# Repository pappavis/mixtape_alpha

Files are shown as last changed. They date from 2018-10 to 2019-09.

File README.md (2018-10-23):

# Wat is Mixtape Alpha?
MixTape Alpga is 'n Atmel328P (Arduino) gebasseerd aanraakgevoelig synth.  Die projekbestande omvat schema bestand vir EagleCAD en diebronkode om dit te laat werk. <br/><br/>
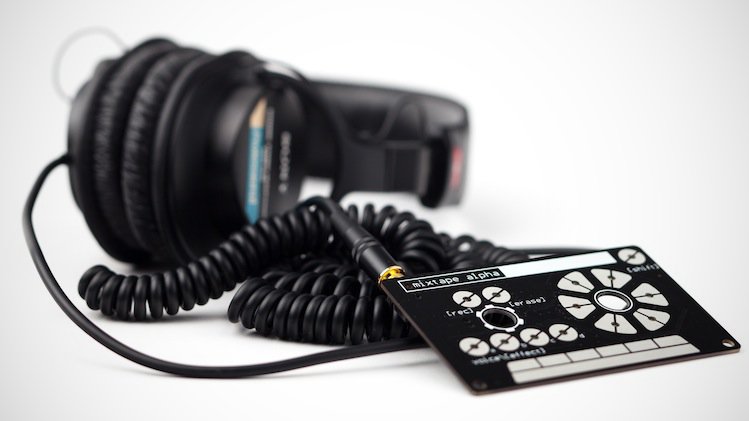
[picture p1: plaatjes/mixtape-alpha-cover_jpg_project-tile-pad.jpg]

<br/>

## Gebruiksinstruksies:<br/>
1. Download EagleCAD<br/>
2. Laai die Schema bestand in Eagle en bekyk dit.<br/>
<br/>

## Printplaat laat maak?<br/>
Om self printplate te laat maak, upload die GERBERs mixtape2_gerber.zip na 'n diens soos http://JLCPCB.com of http://dirtypcbs.com<br/>
<br/>

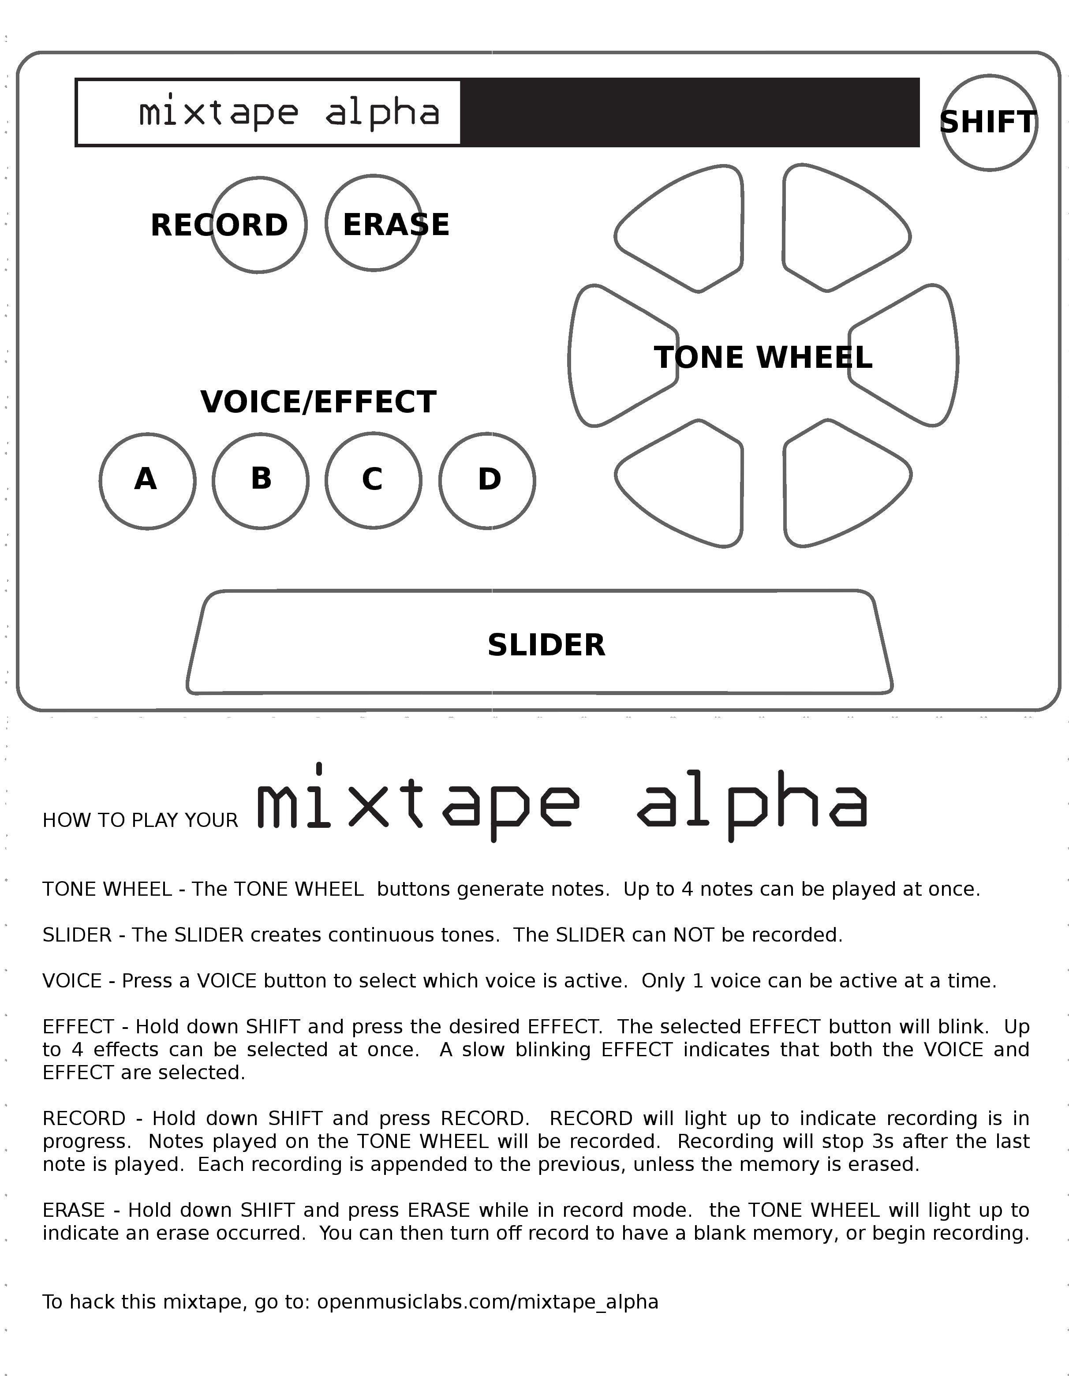
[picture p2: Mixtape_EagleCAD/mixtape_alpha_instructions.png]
<br/>
<br/>

# CREDITS:
Die oorspronklike Mixtape project uit 2013 van MIT Music Lab is op http://wiki.openmusiclabs.com/wiki/MixtapeAlpha<br/>
Ook was daar 'n crowdfunding projek op https://www.crowdsupply.com/open-music-labs/mixtape-alpha <br/>
Ek het dit vir gemak op Github geplaas.<br/>
<br/>

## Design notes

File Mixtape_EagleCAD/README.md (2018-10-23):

## Wat is dit
Dit is die bronbestanden vir EagleCAD en gerbers om by http://jlcpcb.com te laat maak.

## Schema
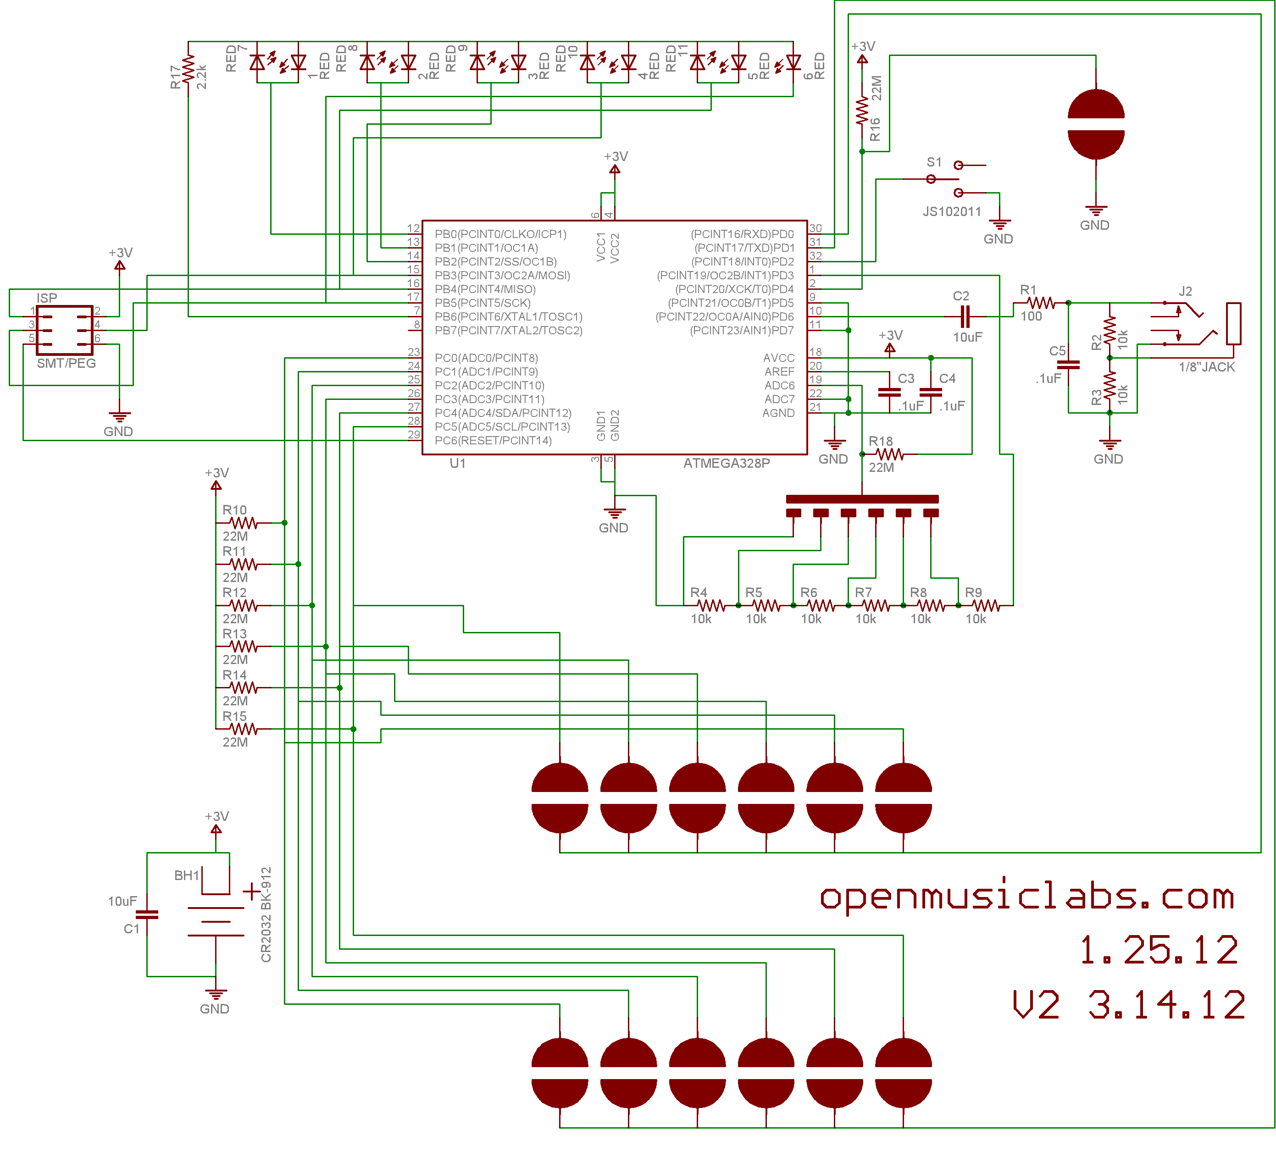
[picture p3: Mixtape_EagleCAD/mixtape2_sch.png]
<br/>
<br/>
## Printplaat boven
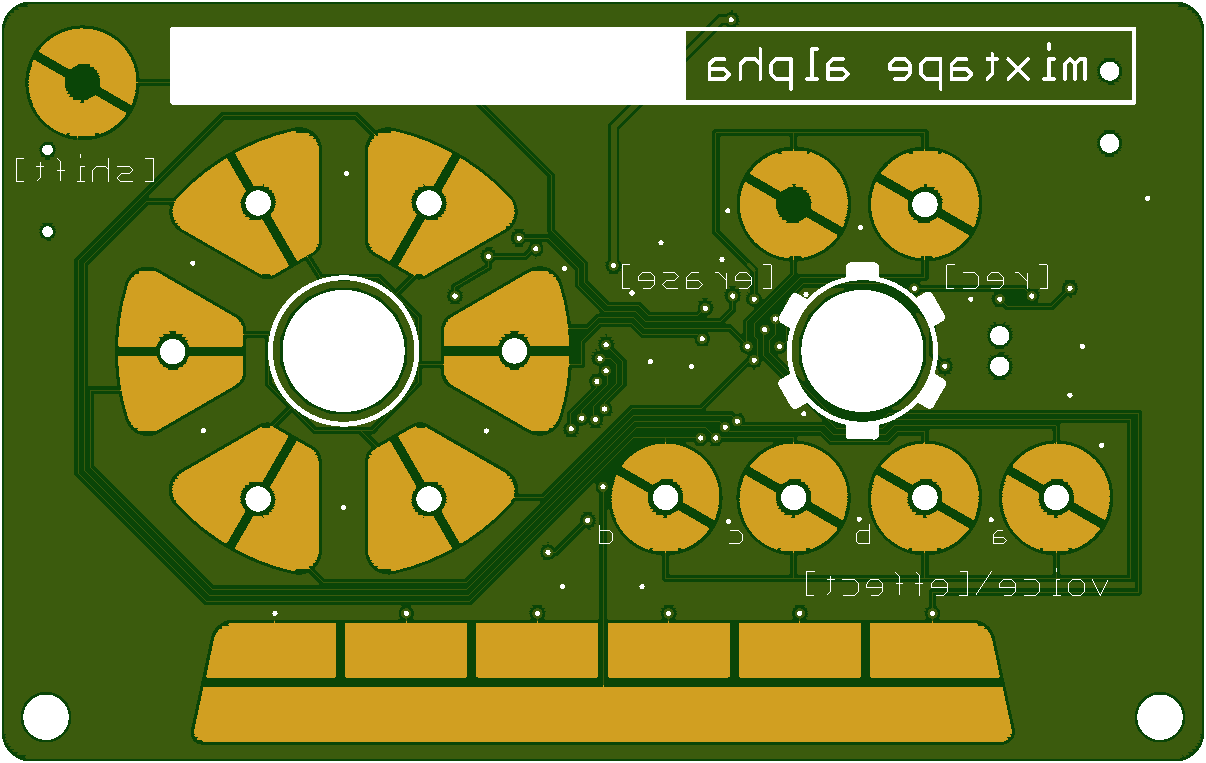
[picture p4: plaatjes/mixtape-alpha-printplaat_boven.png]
 <br/>
<br/>

## Printplaat onder
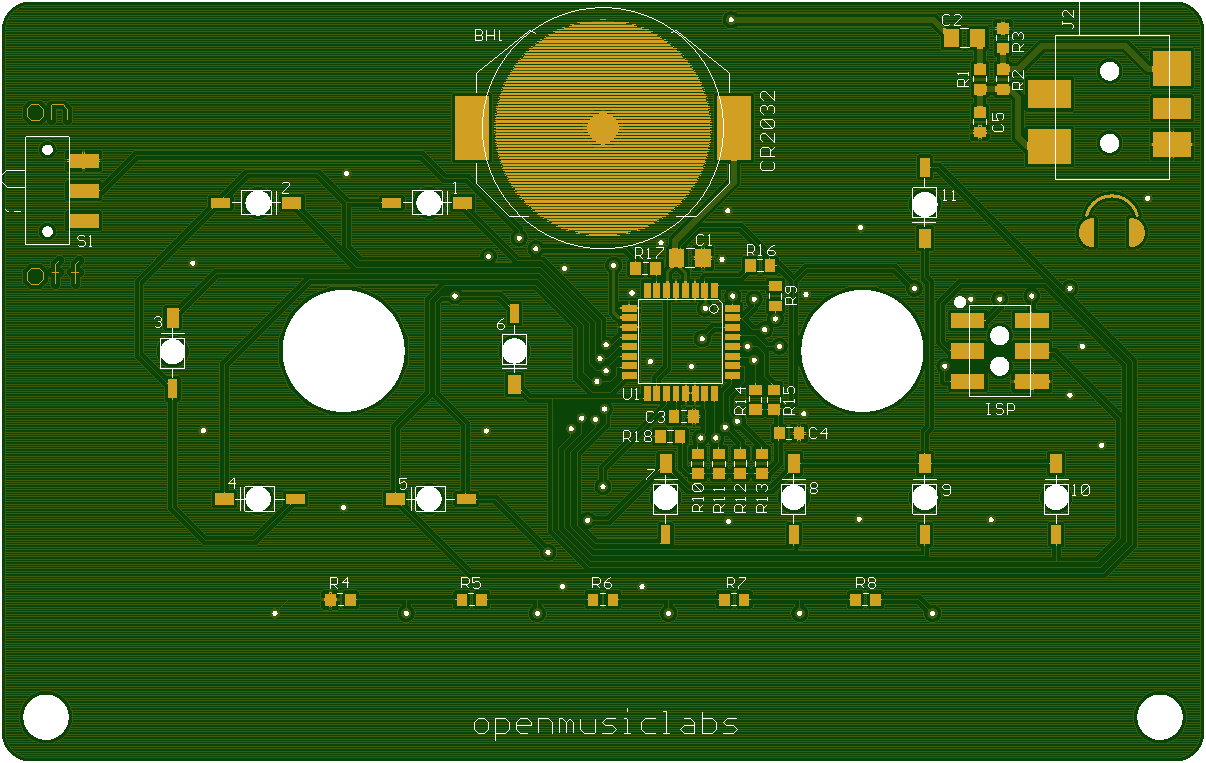
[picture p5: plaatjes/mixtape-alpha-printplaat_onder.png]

<br>

## Dokumentasie
sien wiki op http://wiki.openmusiclabs.com/wiki/MixtapeAlpha <br/>
en algemeen info op http://www.openmusiclabs.com/projects/mixtape_alpha/ <br/>

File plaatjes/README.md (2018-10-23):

Mixtape agterkant met Atmel 328P verwerker;<br/><br/>
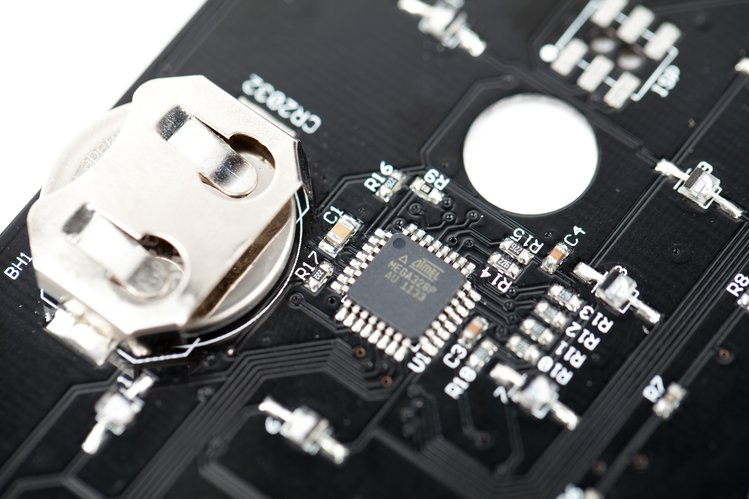
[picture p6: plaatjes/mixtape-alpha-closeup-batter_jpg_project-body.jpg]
<br/>
<br/>
# bord schema ontwerp
<br/>

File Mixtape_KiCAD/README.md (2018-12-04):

<br/>
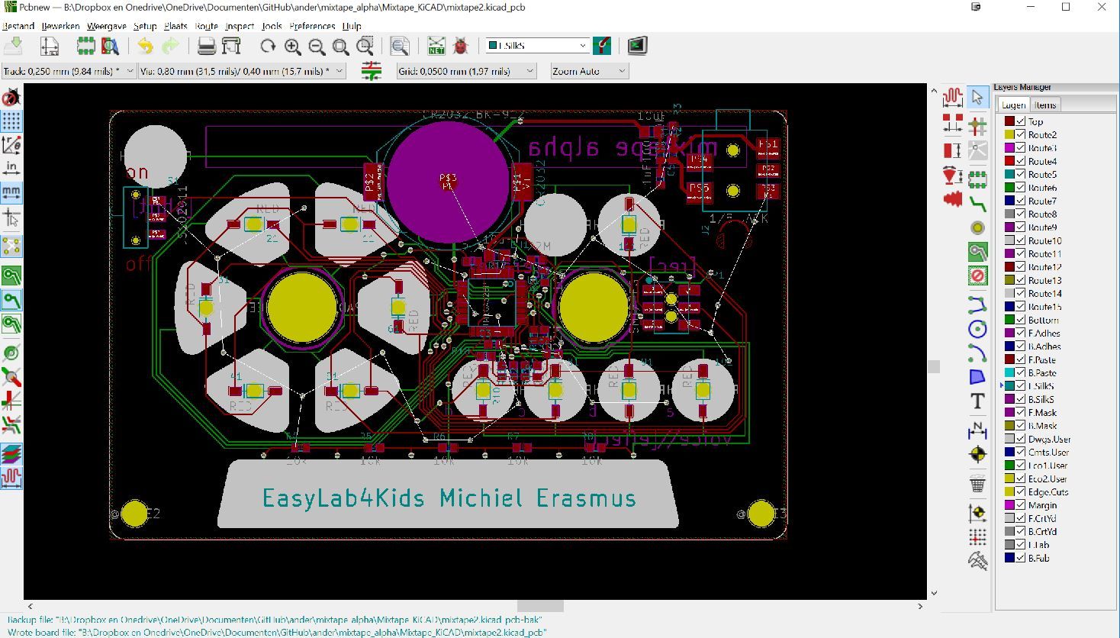
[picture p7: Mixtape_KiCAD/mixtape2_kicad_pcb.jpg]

<br/>

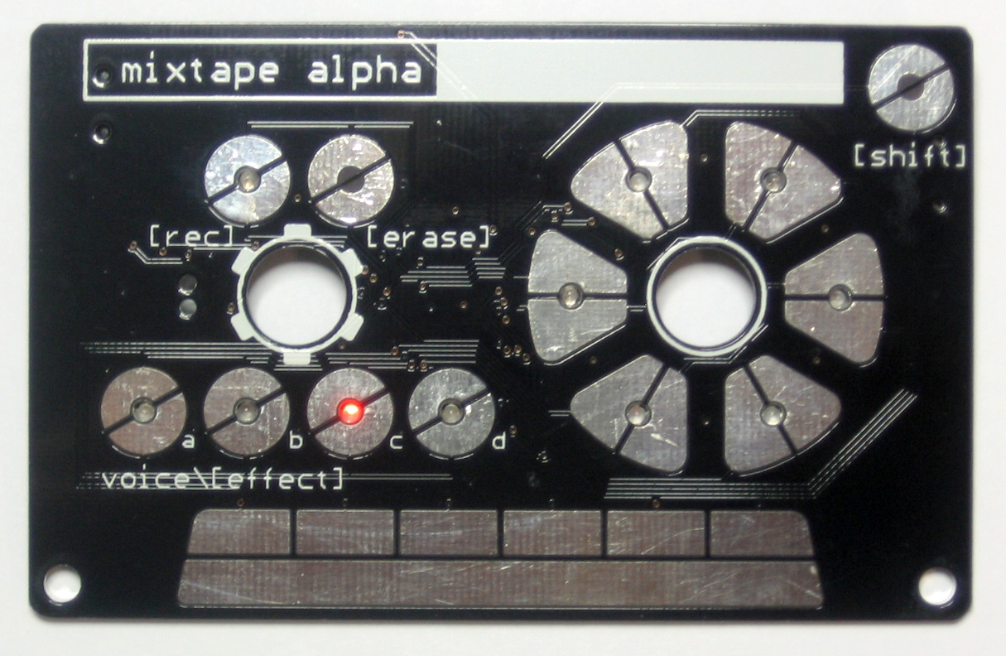
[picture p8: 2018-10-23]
plaatjes/mixtape_top.jpg

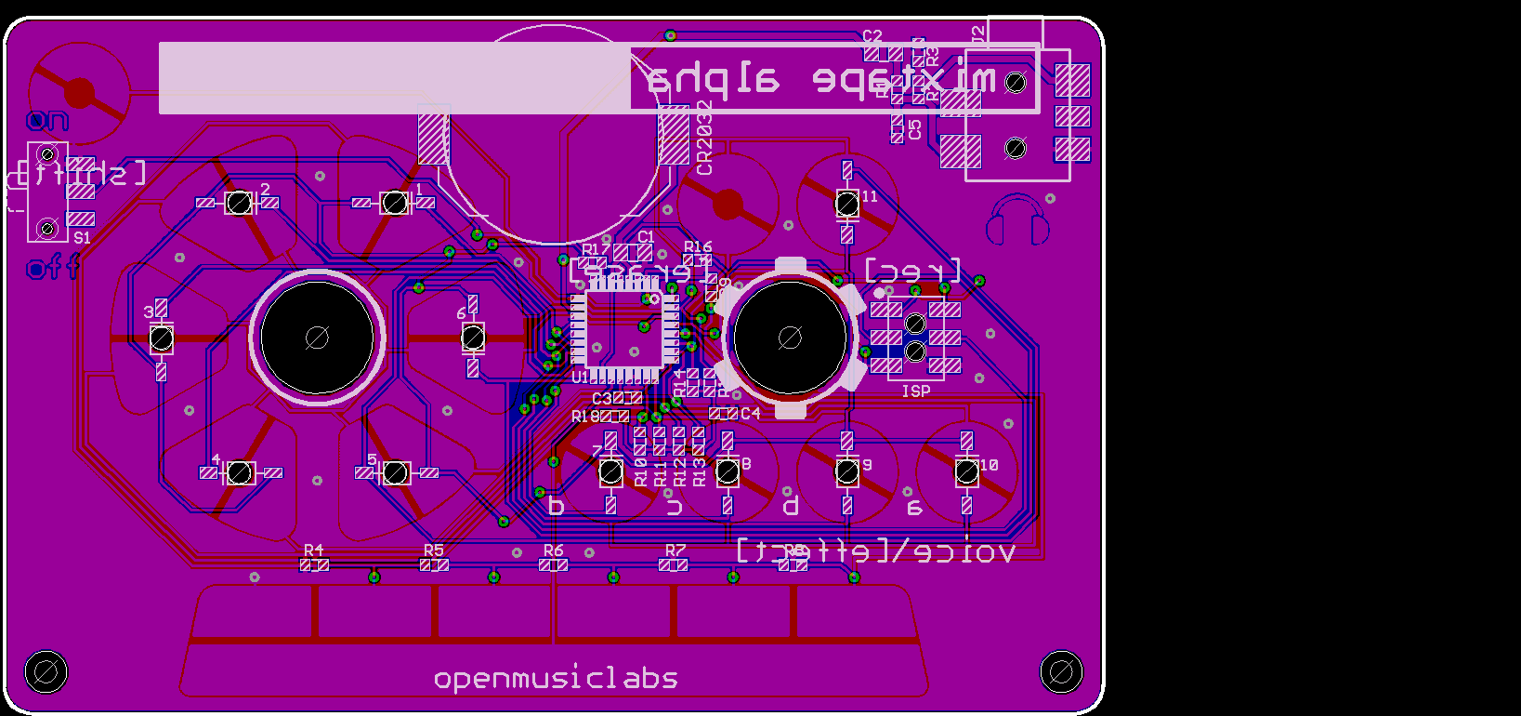
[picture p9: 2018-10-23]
Mixtape_EagleCAD/mixtape2_brd.png

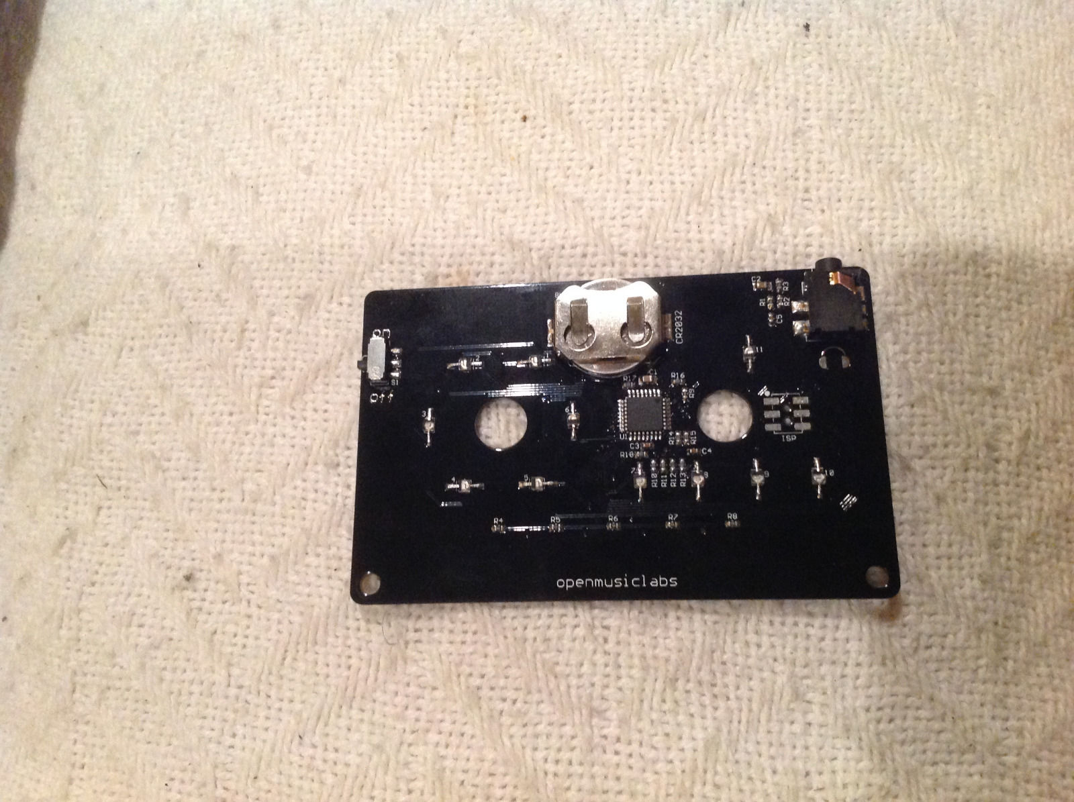
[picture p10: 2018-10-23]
plaatjes/mixtape-alpha-closeup-agter.jpg

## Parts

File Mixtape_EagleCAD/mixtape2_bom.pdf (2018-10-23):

Mixtape1 BOM

DESIGNATOR | PART | VALUE | PACKAGE | DETAILS | PART #
1 | LED | RED | SMT/REVERSE | 25 degree, 482mCd | EVERLIGHT, 91-21SURC/S530-A2/TR10
2 | LED | RED | SMT/REVERSE | 25 degree, 482mCd | EVERLIGHT, 91-21SURC/S530-A2/TR10
3 | LED | RED | SMT/REVERSE | 25 degree, 482mCd | EVERLIGHT, 91-21SURC/S530-A2/TR10
4 | LED | RED | SMT/REVERSE | 25 degree, 482mCd | EVERLIGHT, 91-21SURC/S530-A2/TR10
5 | LED | RED | SMT/REVERSE | 25 degree, 482mCd | EVERLIGHT, 91-21SURC/S530-A2/TR10
6 | LED | RED | SMT/REVERSE | 25 degree, 482mCd | EVERLIGHT, 91-21SURC/S530-A2/TR10
7 | LED | RED | SMT/REVERSE | 25 degree, 482mCd | EVERLIGHT, 91-21SURC/S530-A2/TR10
8 | LED | RED | SMT/REVERSE | 25 degree, 482mCd | EVERLIGHT, 91-21SURC/S530-A2/TR10
9 | LED | RED | SMT/REVERSE | 25 degree, 482mCd | EVERLIGHT, 91-21SURC/S530-A2/TR10
10 | LED | RED | SMT/REVERSE | 25 degree, 482mCd | EVERLIGHT, 91-21SURC/S530-A2/TR10
11 | LED | RED | SMT/REVERSE | 25 degree, 482mCd | EVERLIGHT, 91-21SURC/S530-A2/TR10
U1 | | Atmega328P-AU | 32TQFP
C1 | capacitor | 10uF | 0805 | CERAMIC
C2 | capacitor | 10uF | 0805 | CERAMIC
C3 | capacitor | 0.1uF | 0603 | CERAMIC
C4 | capacitor | 0.1uF | 0603 | CERAMIC
C5 | capacitor | 0.1uF | 0603 | CERAMIC
R1 | resistor | 100ohm | 0603
R2 | resistor | 10k | 0603
R3 | resistor | 10k | 0603
R4 | resistor | 10k | 0603
R5 | resistor | 10k | 0603
R6 | resistor | 10k | 0603
R7 | resistor | 10k | 0603
R8 | resistor | 10k | 0603
R9 | resistor | 10k | 0603
R10 | resistor | 22M | 0603
R11 | resistor | 22M | 0603
R12 | resistor | 22M | 0603
R13 | resistor | 22M | 0603
R14 | resistor | 22M | 0603
R15 | resistor | 22M | 0603
R16 | resistor | 22M | 0603
R17 | resistor | 2.2k | 0603
R18 | resistor | 22M | 0603
S1 | switch | slide | SMT | | C&K, JS102011SAQN
J2 | 1/8” jack | stereo/switched | SMT
BH1 | battery holder | CR2032 | SMT | | MEMORY PROTECTION DEVICES, BK-912

uC

Kobiconn 161-2805-E or CUI SJ1-3515-SMT

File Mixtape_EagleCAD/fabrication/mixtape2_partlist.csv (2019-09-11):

Partlist
Exported from mixtape2.brd at 11-9-2019 18:00
EAGLE Version 9.0.1 Copyright (c) 1988-2018 Autodesk, Inc.
Assembly variant:
Part     Value                  Package               Library  Position (inch)       Orientation
1        RED                    LED-SMT-91-21         audioint (1.405 1.835)         R180
2        RED                    LED-SMT-91-21         audioint (0.845 1.835)         R180
3        RED                    LED-SMT-91-21         audioint (0.565 1.348)         R270
4        RED                    LED-SMT-91-21         audioint (0.845 0.865)         R0
5        RED                    LED-SMT-91-21         audioint (1.405 0.865)         R0
6        RED                    LED-SMT-91-21         audioint (1.685 1.35)          R90
7        RED                    LED-SMT-91-21         audioint (2.18 0.87)           R270
8        RED                    LED-SMT-91-21         audioint (2.6 0.87)            R270
9        RED                    LED-SMT-91-21         audioint (3.03 0.87)           R270
10       RED                    LED-SMT-91-21         audioint (3.46 0.87)           R270
11       RED                    LED-SMT-91-21         audioint (3.03 1.83)           R90
BH1      CR2032 BK-912          BAT-HOLD-BK-912       audioint (1.975 2.08)          R180
C1       10uF                   0805/SMALL            audioint (2.26 1.655)          R180
C2       10uF                   0805/SMALL            audioint (3.16 2.375)          R180
C3       .1uF                   0603-SM               audioint (2.24 1.135)          R0
C4       .1uF                   0603-SM               audioint (2.585 1.08)          R0
C5       .1uF                   0603-SM               audioint (3.21 2.1)            R270
ISP      SMT/PEG                JMP/6P/DIP/SMT/PEG    audioint (3.275 1.35)          R270
J2       1/8"JACK               1/8"JACK/STEREO/SMT   audioint (3.635 2.385)         R0
R1       100                    0603-SM               audioint (3.21 2.24)           R270
R2       10k                    0603-SM               audioint (3.285 2.24)          R270
R3       10k                    0603-SM               audioint (3.285 2.375)         R270
R4       10k                    0603-SM               audioint (1.115 0.535)         R0
R5       10k                    0603-SM               audioint (1.545 0.535)         R0
R6       10k                    0603-SM               audioint (1.975 0.535)         R0
R7       10k                    0603-SM               audioint (2.405 0.535)         R0
R8       10k                    0603-SM               audioint (2.835 0.535)         R0
R9       10k                    0603-SM               audioint (2.54 1.53)           R90
R10      22M                    0603-SM               audioint (2.285 0.98)          R90
R11      22M                    0603-SM               audioint (2.355 0.98)          R90
R12      22M                    0603-SM               audioint (2.425 0.98)          R90
R13      22M                    0603-SM               audioint (2.495 0.98)          R90
R14      22M                    0603-SM               audioint (2.475 1.19)          R90
R15      22M                    0603-SM               audioint (2.535 1.19)          R90
R16      22M                    0603-SM               audioint (2.49 1.63)           R180
R17      100                    0603-SM               audioint (2.115 1.62)          R180
R18      22M                    0603-SM               audioint (2.195 1.07)          R0
S1       JS102011               SWITCH/SLIDE/JS102011 audioint (0.155 1.875)         R270
U$1      PAD/TOUCH/WHEEL        PAD/TOUCH/WHEEL       audioint (1.125 1.35)          MR0
U$2      PAD/TOUCH              PAD/TOUCH/DOT         audioint (2.18 0.87)           MR0
U$3      PAD/TOUCH              PAD/TOUCH/DOT         audioint (2.6 0.87)            MR0
U$4      PAD/TOUCH              PAD/TOUCH/DOT         audioint (3.03 0.87)           MR0
U$5      PAD/TOUCH              PAD/TOUCH/DOT         audioint (3.46 0.87)           MR0
U$6      PAD/TOUCH              PAD/TOUCH/DOT         audioint (3.03 1.83)           MR180
U$7      PAD/TOUCH              PAD/TOUCH/DOT         audioint (2.6 1.83)            MR180
U$8      PAD/TOUCH              PAD/TOUCH/DOT         audioint (0.27 2.23)           MR0
U$9      PAD/TOUCH/SLIDERSLIDER PAD/TOUCH/SLIDER      audioint (1.975 0.265)         MR0
U1       ATMEGA328P             32-TQFP-NOMOD         audioint (2.23 1.38)           R270

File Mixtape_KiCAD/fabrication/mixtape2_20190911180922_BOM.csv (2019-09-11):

ID | Name | Designator | Footprint | Quantity | Manufacturer Part | Manufacturer | Supplier | Supplier Part
1 | PAD/TOUCH/WHEEL | U$1 | PAD/TOUCH/WHEEL | 1
2 | PAD/TOUCH | U$2,U$3,U$4,U$5,U$6,U$7,U$8 | PAD/TOUCH/DOT | 7
3 | PAD/TOUCH/SLIDERSLIDER | U$9 | PAD/TOUCH/SLIDER | 1
4 | 1/8"JACK | J2 | 1/8&quot;JACK/STEREO/SMT | 1
5 | CR2032 BK-912 | BH1 | BAT-HOLD-BK-912 | 1
6 | ATMEGA328P | U1 | 32-TQFP-NOMOD | 1
7 | RED | 2,3,5,8,9,11,1,4,6,7,10 | LED-SMT-91-21 | 11
8 | SMT/PEG | ISP | JMP/6P/DIP/SMT/PEG | 1
9 | 10k | R2,R3,R4,R6,R7,R8,R9,R5 | 0603-SM | 8
10 | 100 | R1,R17 | 0603-SM | 2
11 | 22M | R10,R12,R11,R13,R14,R15,R16,R18 | 0603-SM | 8
12 | 10uF | C2,C1 | 0805/SMALL | 2
13 | .1uF | C3,C4,C5 | 0603-SM | 3
14 | JS102011 | S1 | SWITCH/SLIDE/JS102011 | 1

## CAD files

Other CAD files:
AVR_Studio_project/src/mixtape.obj

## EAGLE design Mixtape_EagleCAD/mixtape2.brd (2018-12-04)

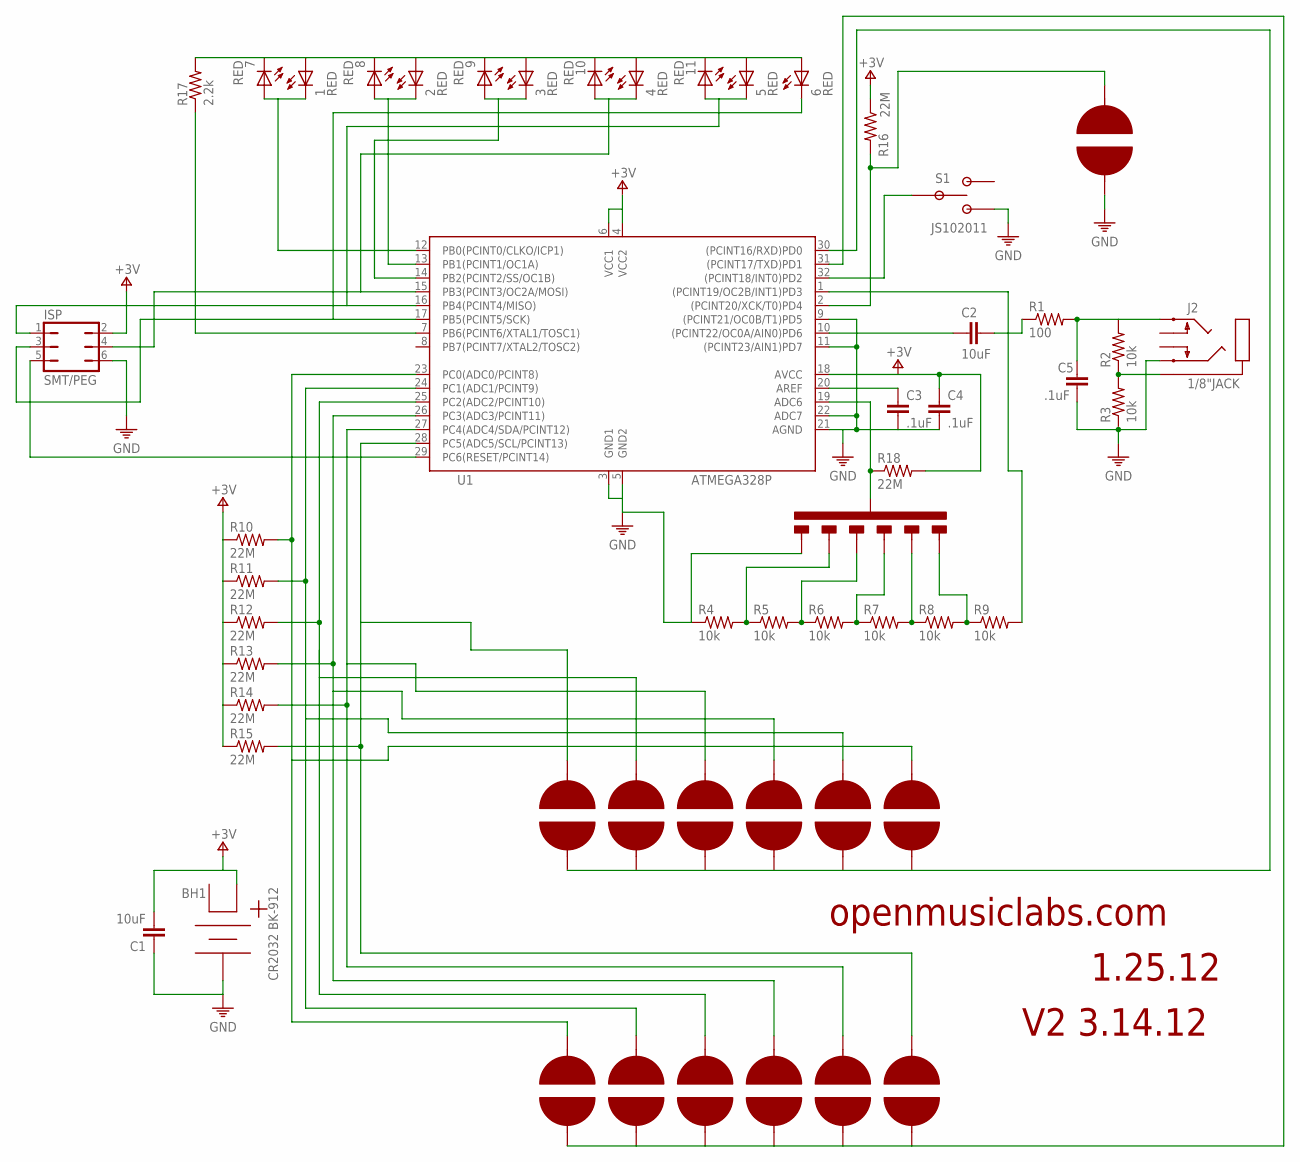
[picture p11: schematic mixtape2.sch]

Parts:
1, 2, 3, 4, 5, 6, 7, 8, 9, 10, 11: RED; LED-SMT-91-21
BH1: CR2032 BK-912; BAT-HOLD-BK-912
C1, C2: 10uF; 0805/SMALL
C3, C4, C5: .1uF; 0603-SM
ISP: SMT/PEG; JMP/6P/DIP/SMT/PEG
J2: 1/8"JACK; 1/8"JACK/STEREO/SMT
R1: 100; 0603-SM
R2, R3, R4, R5, R6, R7, R8, R9: 10k; 0603-SM
R10, R11, R12, R13, R14, R15, R16, R18: 22M; 0603-SM
R17: 2.2k; 0603-SM
S1: JS102011; SWITCH/SLIDE/JS102011
U1: ATMEGA328P; 32-TQFP-NOMOD
U$1: PAD/TOUCH/WHEEL
U$2, U$3, U$4, U$5, U$6, U$7, U$8: PAD/TOUCH; PAD/TOUCH/DOT
U$9: PAD/TOUCH/SLIDERSLIDER; PAD/TOUCH/SLIDER

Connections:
unnamed: R17.P$1 (1), U1.7 (PB6(PCINT6/XTAL1/TOSC1))
unnamed: U1.31 ((PCINT17/TXD)PD1), U$2.P$2, U$3.P$2, U$4.P$2, U$5.P$2, U$6.P$2, U$7.P$2
unnamed: R13.P$2 (2), U1.26 (PC3(ADC3/PCINT11)), U$1.P$7, U$5.P$1
unnamed: U1.30 ((PCINT16/RXD)PD0), U$1.P$2, U$1.P$4, U$1.P$6, U$1.P$8, U$1.P$10, U$1.P$12
unnamed: ISP.5, U1.29 (PC6(RESET/PCINT14))
unnamed: J2.P$1 (1), R2.P$1 (1), R3.P$2 (2)
unnamed: C2.1, R1.P$1 (1)
unnamed: C5.P$1 (1), J2.P$5 (5), R1.P$2 (2), R2.P$2 (2)
unnamed: C2.2, U1.10 ((PCINT22/OC0A/AIN0)PD6)
unnamed: S1.P$2, U1.32 ((PCINT18/INT0)PD2)
unnamed: C3.P$1 (1), U1.20 (AREF)
unnamed: R4.P$2 (2), R5.P$1 (1), U$9.P$6
unnamed: R5.P$2 (2), R6.P$1 (1), U$9.P$5
unnamed: R6.P$2 (2), R7.P$1 (1), U$9.P$4
unnamed: R8.P$2 (2), R9.P$1 (1), U$9.P$2
unnamed: R9.P$2 (2), U1.1 ((PCINT19/OC2B/INT1)PD3)
unnamed: 1.P$1 (C), 7.P$2 (A), U1.12 (PB0(PCINT0/CLKO/ICP1))
unnamed: 2.P$1 (C), 8.P$2 (A), U1.13 (PB1(PCINT1/OC1A))
unnamed: 3.P$1 (C), 9.P$2 (A), U1.14 (PB2(PCINT2/SS/OC1B))
unnamed: 4.P$1 (C), 10.P$2 (A), ISP.4, U1.15 (PB3(PCINT3/OC2A/MOSI))
unnamed: 5.P$1 (C), 11.P$2 (A), ISP.1, U1.16 (PB4(PCINT4/MISO))
unnamed: 1.P$2 (A), 2.P$2 (A), 3.P$2 (A), 4.P$2 (A), 5.P$2 (A), 6.P$2 (A), 7.P$1 (C), 8.P$1 (C), 9.P$1 (C), 10.P$1 (C), 11.P$1 (C), R17.P$2 (2)
unnamed: R16.P$2 (2), U1.2 ((PCINT20/XCK/T0)PD4), U$8.P$1
unnamed: R12.P$2 (2), U1.25 (PC2(ADC2/PCINT10)), U$1.P$3, U$4.P$1
unnamed: R14.P$2 (2), U1.27 (PC4(ADC4/SDA/PCINT12)), U$1.P$5, U$6.P$1
unnamed: R15.P$2 (2), U1.28 (PC5(ADC5/SCL/PCINT13)), U$1.P$1, U$7.P$1
unnamed: R18.P$1 (1), U1.19 (ADC6), U$9.P$1
unnamed: 6.P$1 (C), ISP.3, U1.17 (PB5(PCINT5/SCK))
unnamed: R11.P$2 (2), U1.24 (PC1(ADC1/PCINT9)), U$1.P$9, U$3.P$1
unnamed: R10.P$2 (2), U1.23 (PC0(ADC0/PCINT8)), U$1.P$11, U$2.P$1
unnamed: R7.P$2 (2), R8.P$1 (1), U$9.P$3
PE: BH1.P$3, C1.1, C3.P$2 (2), C4.P$2 (2), C5.P$2 (2), ISP.6, J2.P$3 (2), R3.P$1 (1), R4.P$1 (1), S1.P$1, U1.3 (GND1), U1.5 (GND2), U1.9 ((PCINT21/OC0B/T1)PD5), U1.11 ((PCINT23/AIN1)PD7), U1.21 (AGND), U1.22 (ADC7), U$8.P$2, U$9.P$7
V+: BH1.P$1, C1.2, C4.P$1 (1), ISP.2, R10.P$1 (1), R11.P$1 (1), R12.P$1 (1), R13.P$1 (1), R14.P$1 (1), R15.P$1 (1), R16.P$1 (1), R18.P$2 (2), U1.4 (VCC2), U1.6 (VCC1), U1.18 (AVCC)

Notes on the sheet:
openmusiclabs.com
1.25.12
V2 3.14.12

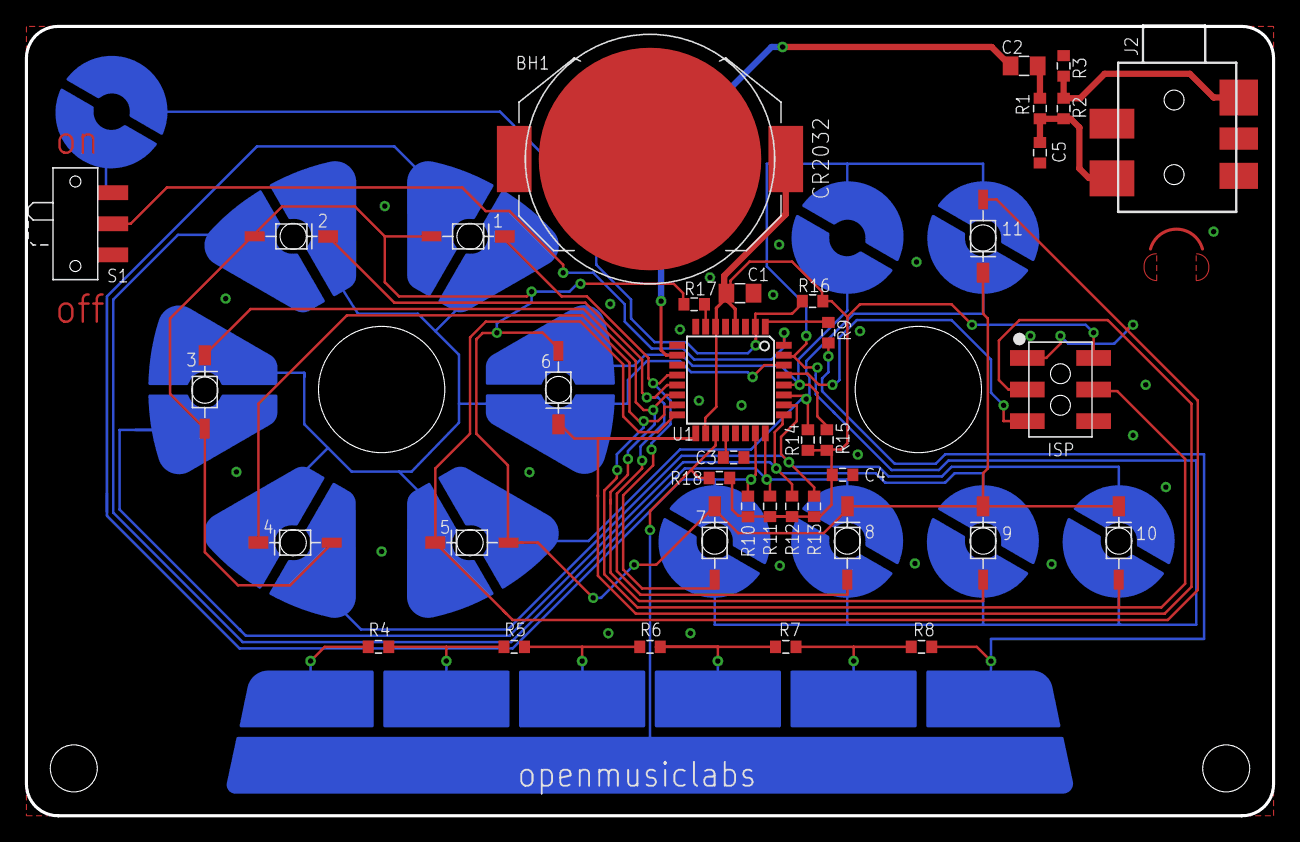
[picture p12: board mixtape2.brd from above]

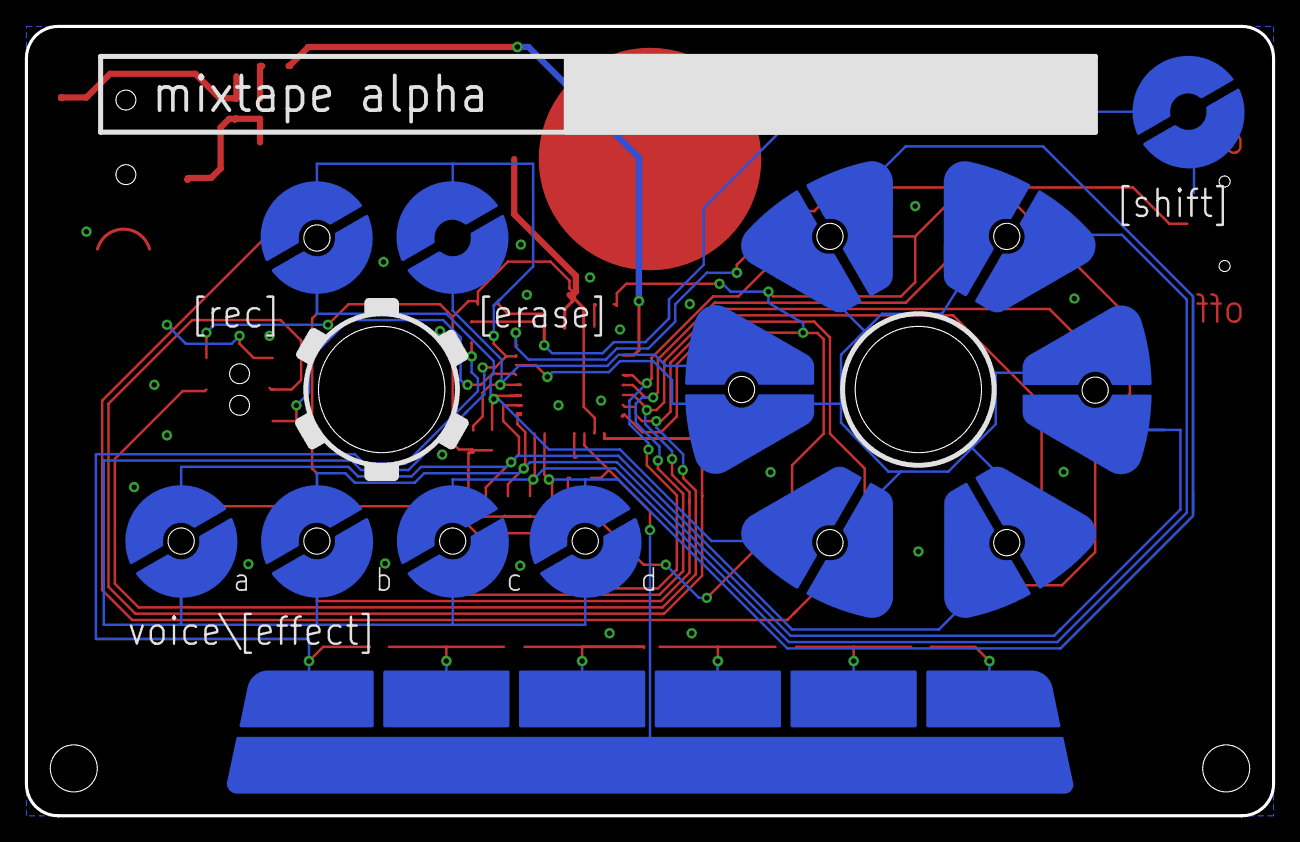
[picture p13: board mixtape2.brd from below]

Board: 2 copper layers, 100.3 x 63.5 mm, 48 parts (9 on the bottom side), 33 nets.

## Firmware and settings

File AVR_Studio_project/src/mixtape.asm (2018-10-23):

.include "m328pdef.inc" ; definitions file

; fuse settings
;
; internal 8MHz RC oscillator, slowest startup time
; isp enabled
; brownout disabled
; no boot reset
; no memory locks

; pin usage
;
; pb0:5 = led1:6, led7:11
; pb6   = led direction, 1 = led1:6, 0 = led7:11
; pb7   = nc
; pc0:5 = pad1:6, pad7:12
; pc6   = reset
; pd0   = pad1:6 control, 0 = active, 1 = off
; pd1   = pad7:12 control, 0 = active, 1 = off
; pd2   = power switch, 0 = on, 1 = off, int0
; pd3   = slider control, 1 = on, 0 = off
; pd4   = shift pad
; pd5,7 = shorted to ground, always set to input, pullups off
; pd6   = pwm out, oc0a, t0
; adc6  = slider analog input
; adc7  = nc
; aref  = cap, internal vcc

; hardware
;
; led1:6 correspond to pad1:6, and are on the wheel
; led7:11 correspons to pad7:12, and are the voice/rec/erase - erase does not have an led

; register usage
;
; r0  = multiply result lsb - do not use in main (not backed up)
; r1  = multiply result msb - do not use in main (not backed up)
; r2  = voice 1 pointer lsb
; r3  = voice 1 pointer msb
; r4  = voice 2 pointer lsb
; r5  = voice 2 pointer msb
; r6  = voice 3 pointer lsb
; r7  = voice 3 pointer msb
; r8  = voice 4 pointer lsb
; r9  = voice 4 pointer msb - do not touch these anywhere but t0
; r10 = null register
; r11 = led scan position - only for t2
; r12 = led1:6 state register (inverted logic - b7:6 always set) - write only, except t2
; r13 = led7:11 state register - write only, except t2
; r14 = voice 5 pointer lsb
; r15 = voice 5 pointer msb - do not touch these anywhere but t0
; r16 = main general swap register - main only
; r17 = main general swap register - main only
; r18 = t0 storage register - t0 only
; r19 = interrupt swap register - interrupts only
; r20 = tone 1 rate
; r21 = tone 2 rate
; r22 = tone 3 rate
; r23 = tone 4 rate
; r24 = tone 5 rate - write only, except t0
; r25 = main general swap register -  main only
; r26 = delay table pointer lsb
; r27 = delay table pointer msb - t0 only
; r28 = sequencer pointer lsb
; r29 = sequencer pointer msb - main only
; r30 = lookup table address lsb
; r31 = lookup table address msb - backed up in interrupts
; gpior0 = sreg storage during t0 interrupt - t0 only
; gpior1 = pad2 effect/rec/erase state - read only, except main
; gpior2 = pad2 voice state - read only, except main
; eedr = current note voice - read only, except main
; eearl = lfo value register - read only, except t2


; sram usage
;
; $0100 - $01ff = pattern memory
; $0200 - $07ff = delay memory
; $0800 - $08ef = variable storage
; $08f0 - $08ff = stack

.include "mixtape_defs.inc" ; definitions file with sram usage


; pattern storage format
;
; byte0 = time till next note
; byte1 = note voice
; byte2 = note frequency
; byte3 = led pattern

.org $0000
rjmp init ; initialization
.org INT0addr
jmp wakeup ; on/off switch handler
.org OC2Aaddr
rjmp t2int_led ; led handler
.org OC2Baddr
rjmp t2int_led ; led handler
.org OVF2addr
rjmp t2int_lfo ; fm/am vco handler
.org OVF1addr
rjmp t1int ; main loop timer - not used, checked in main loop
.org OVF0addr
rjmp t0int ; sample playback handler

init: ; stuff done only on reset

ldi r16,$00
out gpior1,r16 ; set effect/rec state to off
sts pattern_top_lsb,r16
ldi r16,$01
sts pattern_top_msb,r16  ; set pattern point to start - empty pattern

start: ; initialize all the stuffs

cli ; in case interrupts are on
ldi r16,$00
out smcr,r16 ; clear the sleep mode register to be on the safe side

;move stack point to end of sram (for now, will put it elsewhere later)
ldi r16,high(ramend)
out sph,r16
ldi r16,low(ramend)
out spl,r16

;initialize ports
ldi r16,$80
out portb,r16 ; set all of portb to 0, except unused pin
ldi r16,$7f
out ddrb,r16 ; set portb to output, except unused pin
ldi r16,$40
out portc,r16 ; turn off pullups for portc, except reset pin
ldi r16,$00
out ddrc,r16 ; set all of portc to input
ldi r16,(0<<pd7)|(0<<pd6)|(0<<pd5)|(1<<pd4)|(1<<pd3)|(1<<pd2)|(1<<pd1)|(1<<pd0)
out portd,r16 ; pullups on for pd2,4 high for pd0,1,4, low for all else
ldi r16,$4b
out ddrd,r16 ; pd0,1,3,6 output, rest input

;setup power reduction registers
ldi r16,$86
sts prr,r16 ; turn off twi,usart,spi

;setup t0 for pwm (31.25khz)
ldi r16,$83
out tccr0a,r16 ; set to noninverted mode, oc0a compare match
ldi r16,$01
out tccr0b,r16 ; set to fast pwm mode, ck = Fcpu = 8MHz
ldi r16,$01
sts timsk0,r16 ; turn on the overflow interrupt

;commented out for the time being - if you erase it, change power register
;setup t1 for button scan timing and state update
;ldi r16,$00
;sts tccr1a,r16
;ldi r16,$13
;sts tccr1b,r16 ; set to pwm phase/freq correct, top = icr1, ck = Fcpu/64
;ldi r16,$00
;sts tccr1c,r16
;ldi r16,$08
;sts icr1h,r16
;ldi r16,$00
;sts icr1l,r16 ; set counter top to $0800 (30.5hz)
;ldi r16,$00 ; main checks buttons every other - so 15hz scan rate
;sts timsk1,r16 ; turn off overflow interrupt

;setup t2 for lfo, button, and led scan timing
;293hz for lfo scan, 880hz (16x55hz) for led/button scan
ldi r16,$01
sts tccr2a,r16
ldi r16,$0c
sts tccr2b,r16 ; set to pwm phase/freq correct, top = 0cr2a, ck = Fcpu/64
ldi r16,$d5
sts ocr2a,r16 ; set counter top to $d5
ldi r16,$55
sts ocr2b,r16 ; set interrupt to 1/3 max, $47
ldi r16,$07
sts timsk2,r16 ; turn on overflow, ocr2a, ocr2b interrupts

;setup adc to read slider
ldi r16,$66
sts admux,r16 ; set to internal vref = vcc, sample adc6, left adjust result
ldi r16,$c7
sts adcsra,r16 ; turn on adc, single sample mode, ck = Fcpu/128 = 62.5kHz
ldi r16,$00
sts adcsrb,r16 ; free running mode

;setup registers
ldi r16,$40
sts buttondata_counter,r16 ; set button counter to top
ldi r16,$50
sts buttondata_pointer,r16 ; set button data pointer to bottom
ldi r16,$01
mov r11,r16 ; led scan bit
ldi r16,$ff
mov r12,r16 ; turn all leds off
ldi r16,$00
mov r10,r16 ; initialize null register
sts pad1_state,r10
sts pad2_state,r10
sts pad1_prev,r10
sts pad2_prev,r10 ; set all buttons to off
out gpior0,r10
in r16,gpior1
andi r16,$0f
out gpior1,r16 ; clear record/erase bits
ldi r16,$08
out gpior2,r16 ; set synthstate to voice a
mov r13,r16 ; turn voice a led on
ldi r16,$0c
out eedr,r16 ; set voice to a
sts note_trigger,r10 ; set notes to off
sts note1_voice,r16
sts note2_voice,r16
sts note3_voice,r16
sts note4_voice,r16 ; set all voices to sine
ldi r26,$00
ldi r27,$02 ; initialize delay pointer
ldi r28,$00
ldi r29,$01 ; initialize pattern pointer
sts note_amp_state,r10 ; set all notes to off
sts note1_amp,r10
sts note2_amp,r10
sts note3_amp,r10
sts note4_amp,r10 ; set all notes to off
clr r20
clr r21
clr r22
clr r23
clr r24 ; set all notes to off
ldi r16,$40
sts note_counter,r16 ; set note counter to start 1s after start
ldi r16,$03
sts fm_value,r16 ; set fm vlaue
sts note_scheduler,r10 ; set all notes free
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

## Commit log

2018-10-23 Eerste toevoeging 20181023
    [mixtape.obj, mixtape2.sch, mixtape2_bom.ods]
2018-11-12 Eagle BRD toegevoegd
    [mixtape2.brd]
2018-12-04 Bygewerkt na EagleCAD 9 formaat
    [mixtape2.sch]
2018-12-04 KiCAD 5.0-versie
    [mixtape2.kicad_pcb, mixtape2.sch]
2019-09-11 Eerste commit
    Bill of materials
    [mixtape2_bom.csv]
2019-09-11 Pick n place bestande toegevoegd.
    [mixtape2_20190911180922_BOM.csv, mixtape2_partlist.csv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]
